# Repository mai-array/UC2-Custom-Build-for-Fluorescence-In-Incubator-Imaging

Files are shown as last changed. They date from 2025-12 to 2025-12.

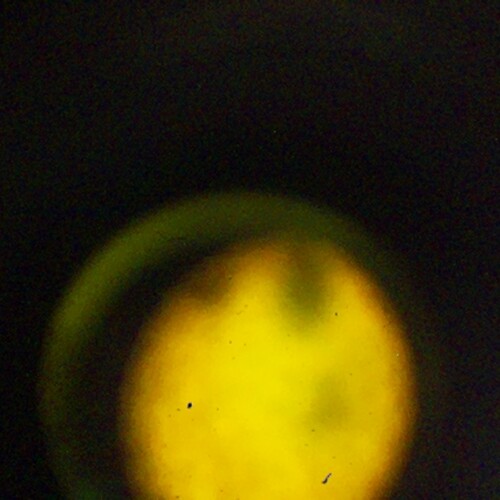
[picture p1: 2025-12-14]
Image Collections/Initial Attempts/PreIncTest/PreIncTest5.jpg

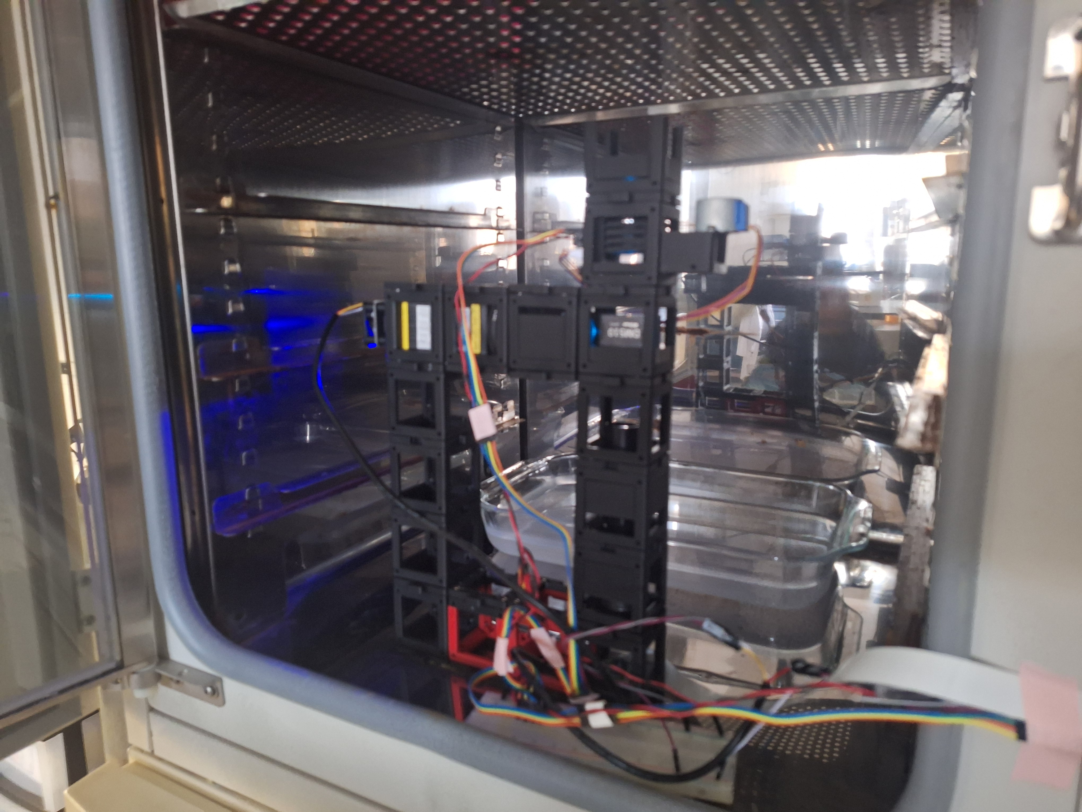
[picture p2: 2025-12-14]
Full Microscope Tests/in_incubator1.jpg

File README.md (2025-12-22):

A 3D Printed Modular Microscope for In-Incubator Time-lapse Fluorescence Imaging

Maitreyi Vadigepalli1,2, Kiril Bahadure1, Janice Walker1

1Department of Pathology and Genomic Medicine, Sidney Kimmel Medical College, Thomas Jefferson University, Philadelphia, PA

2Westtown School, Westtown, PA

We aim to develop a low-cost fluorescence microscope capable of obtaining time-lapse images of cell biology processes in vivo within a cell incubator setting. The commercial systems for fluorescence microscopy are expensive and require extensive setup for use in incubators. In recent years, 3D printing technology has enabled affordable alternatives to traditional frame structures and rigs, based on which multiple open-source frameworks have emerged for building low-cost, laboratory-grade microscopes. We used the open-source UC2 framework to develop a modular microscope tailored to fluorescent imaging within an incubator. We adopted standardized modules for the motor-controlled objective z-stepper, the Raspi camera, and a mirror, and developed custom-built modules for the laser, neutral density filter, beam expander, dichroic beamsplitter, tube lens, and sample holder. The initial version was built for benchtop imaging in a minimalist approach containing only a sample holder, objective, and Raspi camera module. This allowed us to optimize the software for controlling the motor to focus the objective. In subsequent iterations, we developed customized drop-in modules for fluorescent imaging. The current version features infinity optics, allowing placement of additional optical components between the camera and the objective. These modules can be combined in multiple ways based on the physical constraints of the incubator and the desired light path. The assembled microscope is controlled by a Raspberry Pi device. We developed Python code to control the objective z-stepper and the laser, as well as to coordinate between the two modules for automated time-lapse image capture. We are testing the system to image the cellular response to wounding in an ex vivo chick post-cataract surgery explant system, an established experimental model for studying the lens response to cataract surgery-induced wounding. We are visualizing cell boundaries using fluorescently conjugated Wheat Germ Agglutin, a lectin that demarcates cell membranes by binding GlcNAc and sialic acid residues. We are collecting images of the lens cellular response to wounding over 3 days, a typical period for wound closure. In summary, we demonstrate a modular, reconfigurable, 3D-printed microscope custom-built for in-incubator time-lapse fluorescence imaging for cell biology applications.

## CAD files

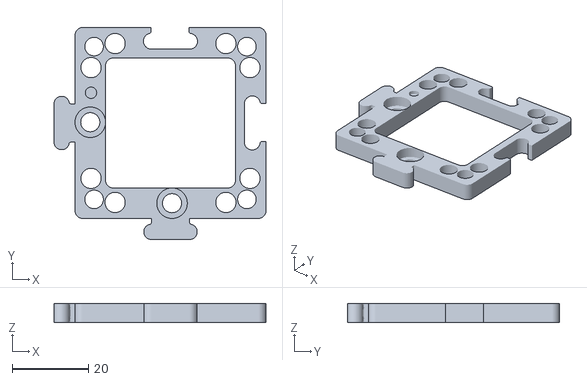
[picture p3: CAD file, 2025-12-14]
CAD Models/Cube + Baseplane - UC2/0_10_Base_puzzle_v3.stl
55.5 x 55.5 x 5.00

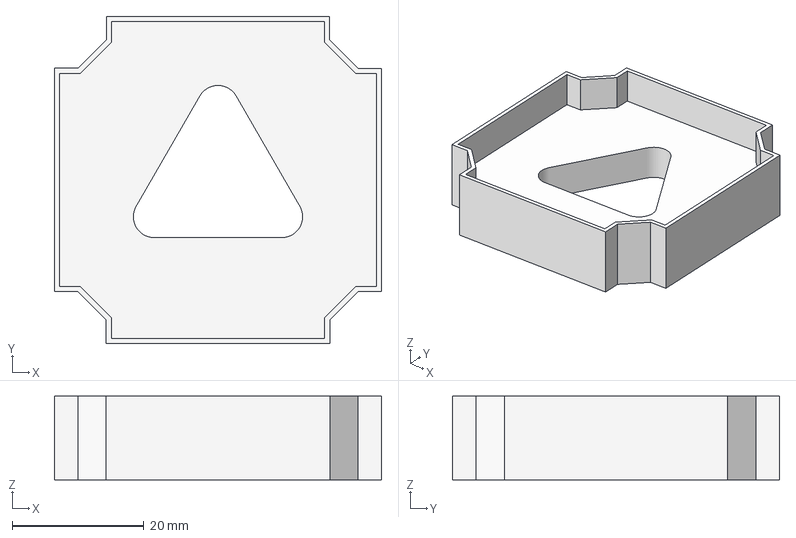
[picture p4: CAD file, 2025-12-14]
CAD Models/Sample Holder V5 - Custom.3mf
49.6 x 49.6 x 12.7 mm

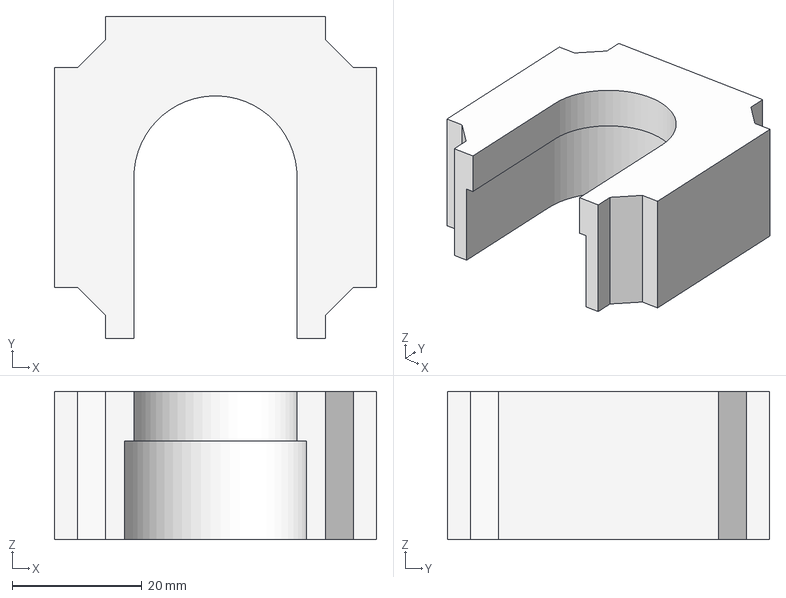
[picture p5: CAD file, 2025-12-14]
CAD Models/Tube Lens - Custom/Tube Lens P2 V2 - Custom.3mf
49.6 x 49.6 x 22.9 mm

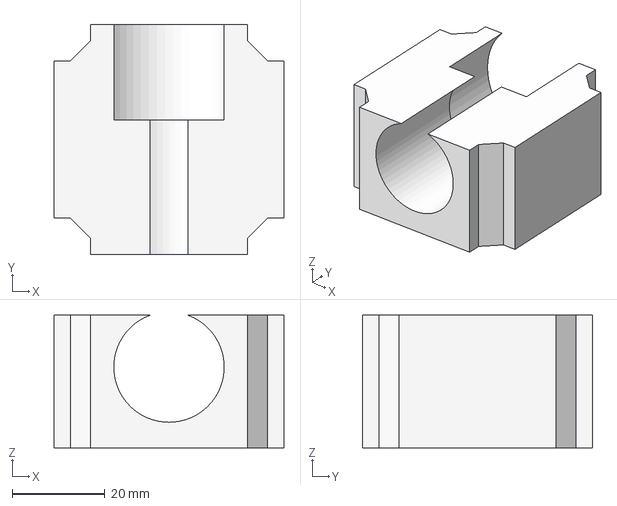
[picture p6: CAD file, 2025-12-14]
CAD Models/Beam Expander V2 - Custom.3mf
49.6 x 49.6 x 28.6 mm

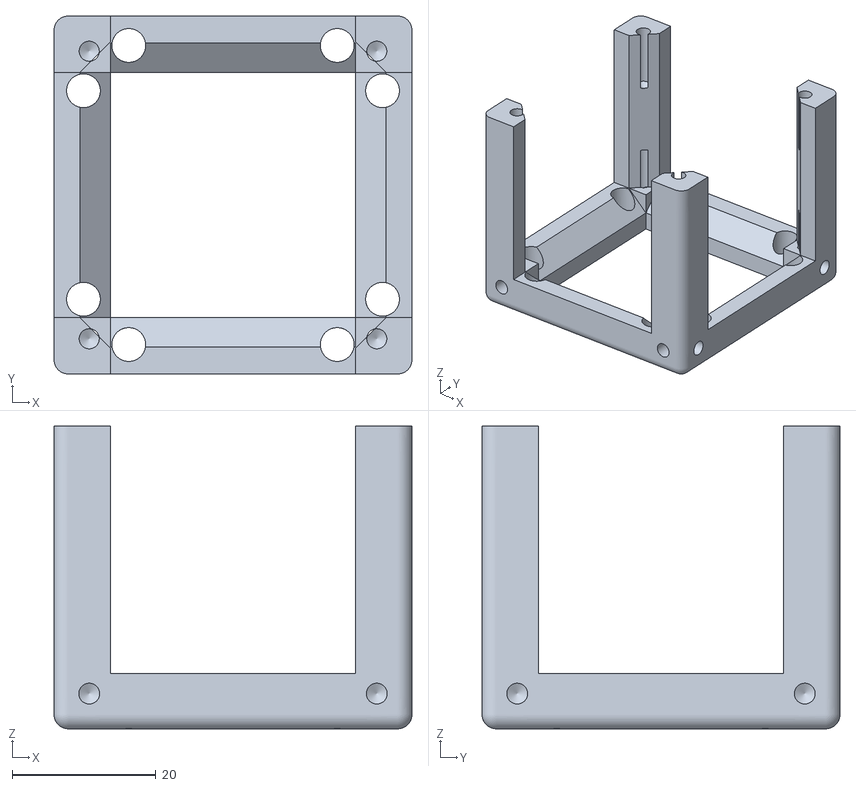
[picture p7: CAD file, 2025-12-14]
CAD Models/Cube + Baseplane - UC2/1_10_Cube_1x1_v3.stl
49.8 x 49.8 x 42.1

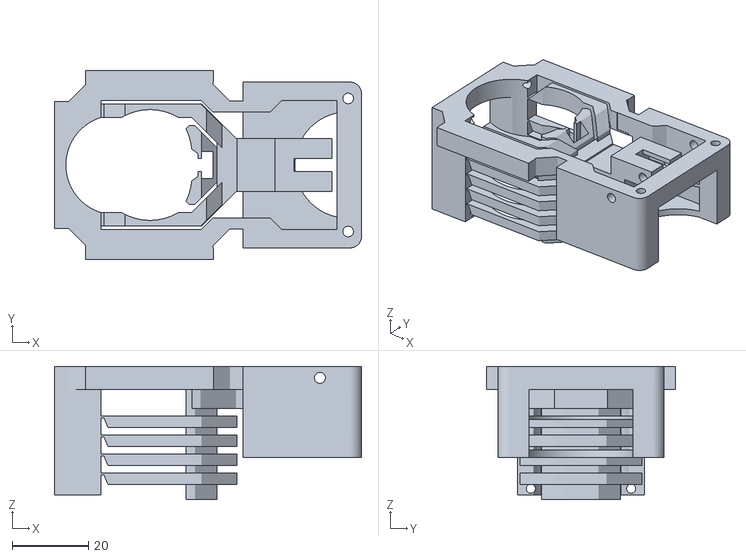
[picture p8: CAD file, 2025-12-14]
CAD Models/Objective Z-Stepper - UC2/2_20_focus_inlet_linearflexure_motorized_small_v3.stl
80.7 x 49.8 x 35.0

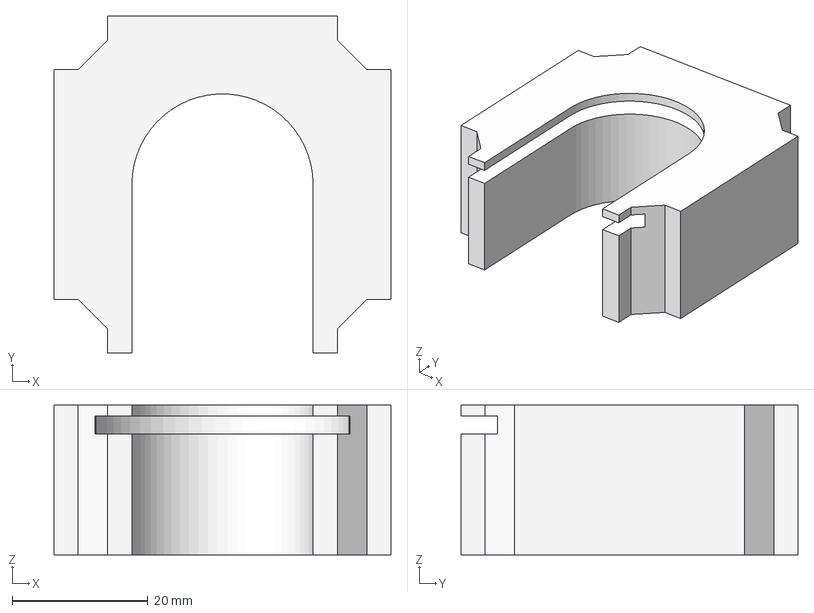
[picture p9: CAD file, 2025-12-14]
CAD Models/Tube Lens - Custom/Tube Lens P1 V2 - Custom.3mf
49.6 x 49.6 x 22.0 mm

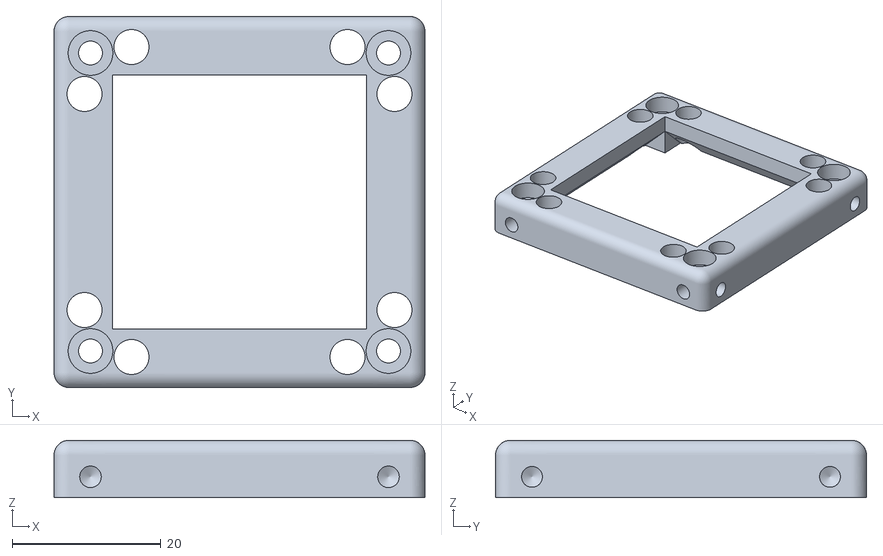
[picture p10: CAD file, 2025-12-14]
CAD Models/Cube + Baseplane - UC2/4_10_Lid_1x1_v3.stl
49.8 x 49.8 x 7.70

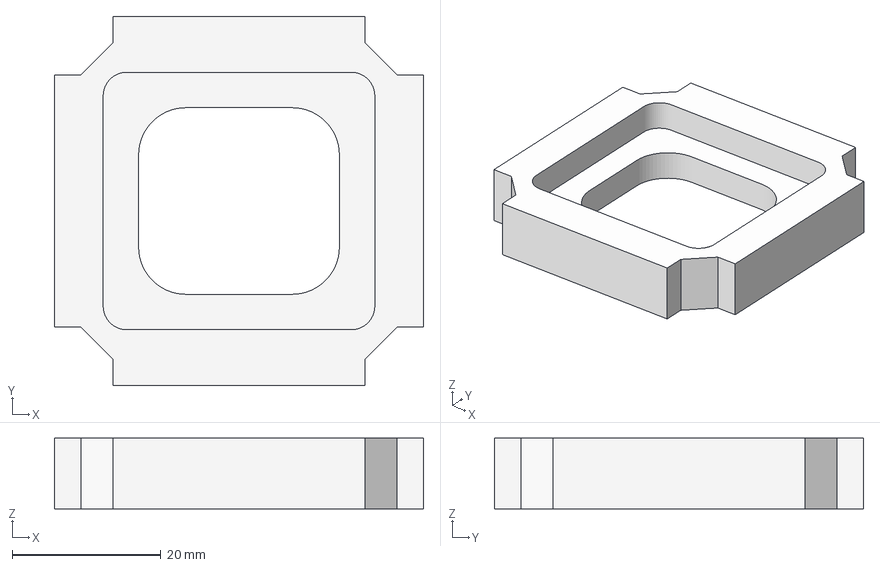
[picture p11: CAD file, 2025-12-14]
CAD Models/Dichroic Beam Splitter V5 - Custom.3mf
49.6 x 49.6 x 9.52 mm

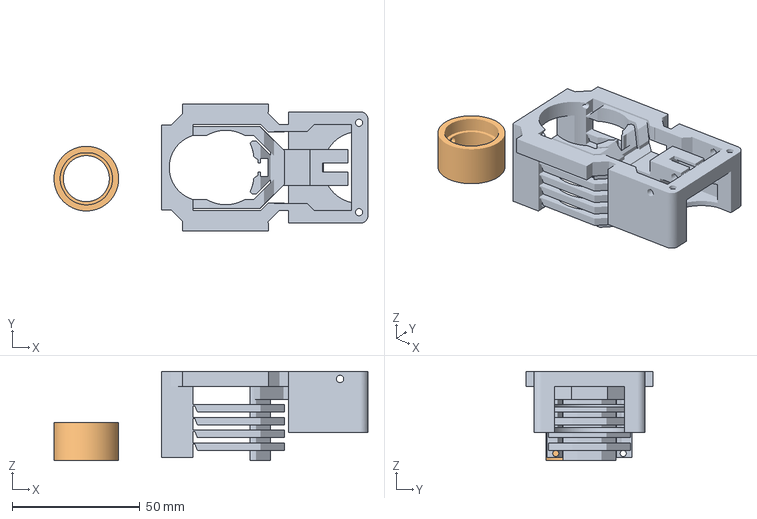
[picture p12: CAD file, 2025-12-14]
CAD Models/Objective Z-Stepper - UC2/0_20_focus_inlet_objective_mount_v8_v3.3mf
122.8 x 49.8 x 35.0 mm
2_20_focus_inlet_linearflexure_motorized_small_v3.stl
0_20_focus_inlet_objective_mount_v8_v3.stl

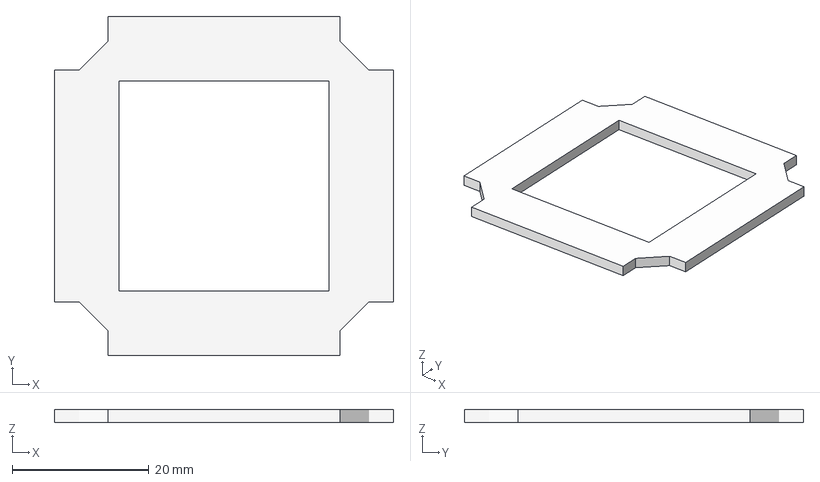
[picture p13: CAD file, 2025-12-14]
CAD Models/488nm Laser Mount V3 - Custom.3mf
49.6 x 49.6 x 1.90 mm

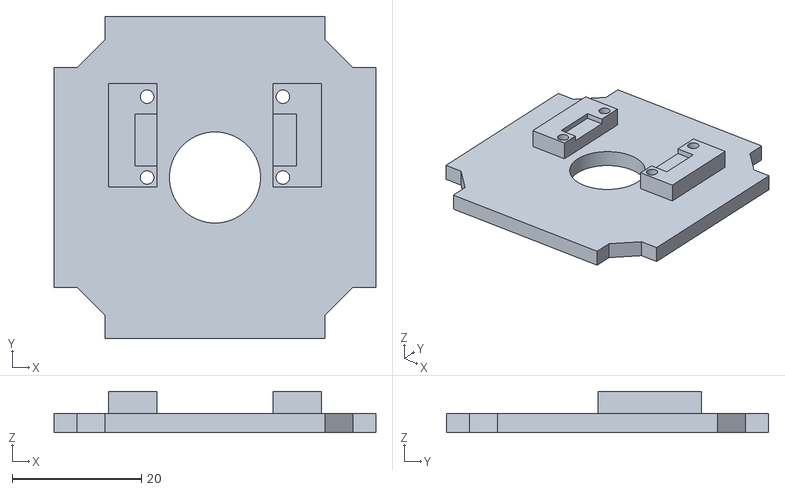
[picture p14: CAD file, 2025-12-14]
CAD Models/1_20_Cube_Insert_RaspiCam_v3 - UC2.stl
49.8 x 49.8 x 6.40

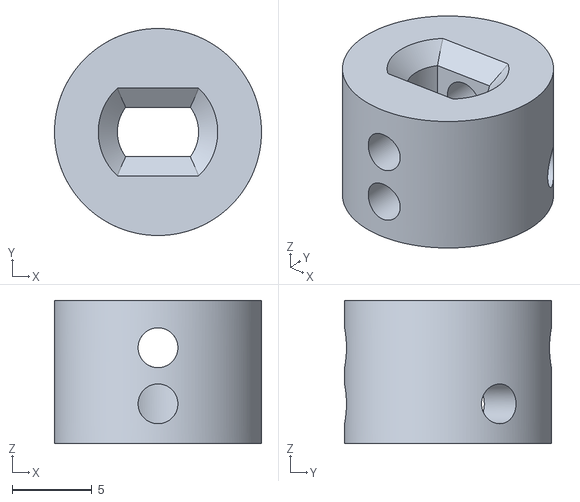
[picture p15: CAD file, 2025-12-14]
CAD Models/Objective Z-Stepper - UC2/3_30_Coupling_Screw_28BYJ_M3_v3.stl
13.0 x 13.0 x 9.00

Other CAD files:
CAD Models/Objective Z-Stepper - UC2/0_20_focus_inlet_objective_mount_v8_v3.stl

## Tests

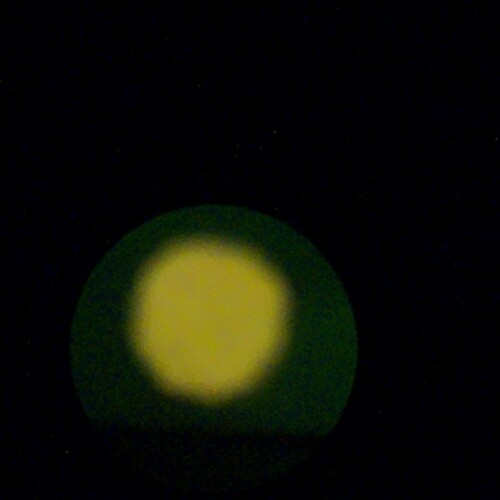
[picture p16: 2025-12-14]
Image Collections/Infinity Tests/1st Infinity Test/infinityTest7.jpg

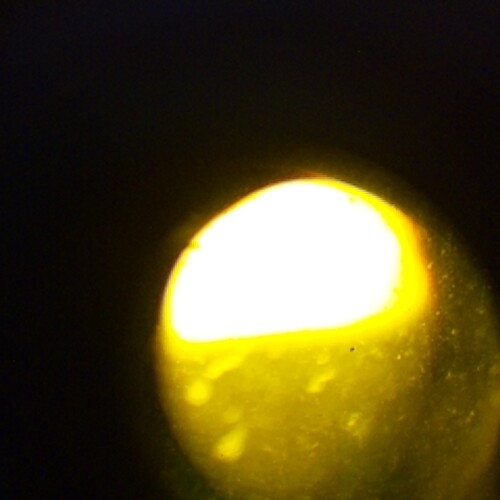
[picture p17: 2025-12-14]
Image Collections/Focusing Tests/focusTest1/focusTest14.jpg

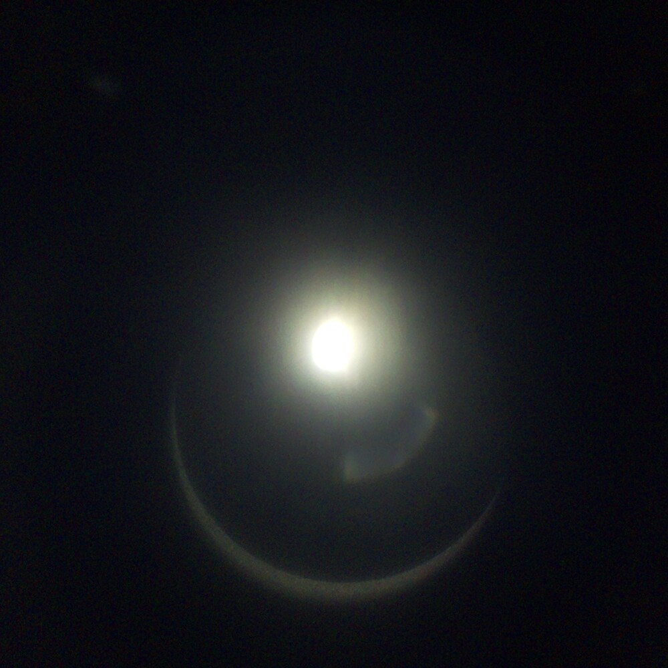
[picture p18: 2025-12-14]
Image Collections/Infinity Tests/1st Infinity Test/testimage.jpg

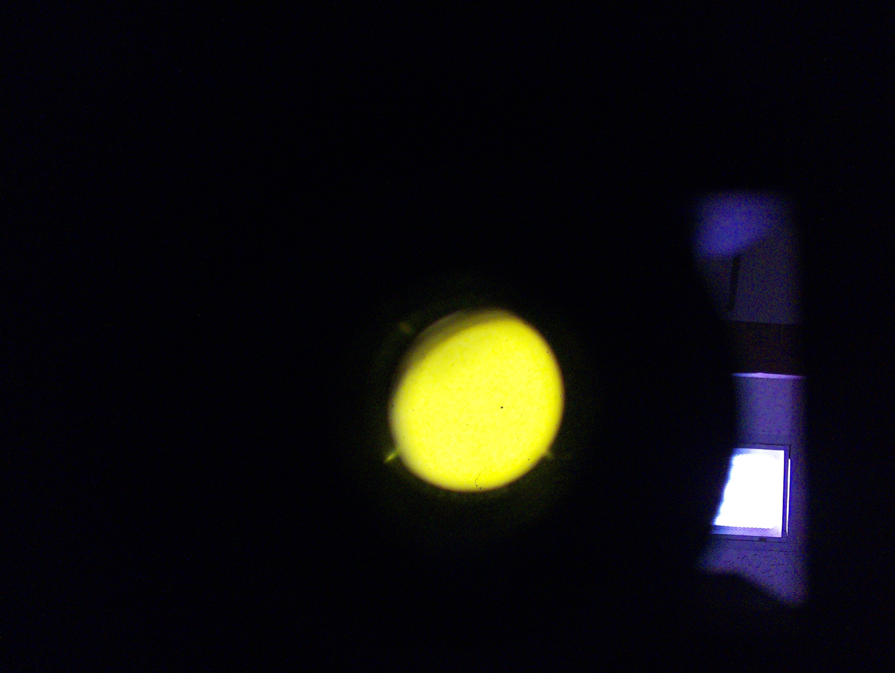
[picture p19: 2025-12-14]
Image Collections/Infinity Tests/2nd Infinity Test/infinityTestV2_6.jpg

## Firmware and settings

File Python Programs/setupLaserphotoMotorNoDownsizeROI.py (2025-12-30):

import RPi.GPIO as GPIO
import time
import os
from picamera2 import Picamera2

# -------------------- Camera Setup --------------------
home_dir = os.environ['HOME']
save_dir = os.path.join(home_dir, "Desktop")

picam2 = Picamera2()

# Sensor + ROI parameters (Camera Module v2 / IMX219)
SENSOR_WIDTH = 3280
SENSOR_HEIGHT = 2464

ROI_SIZE = 1000  # true sensor ROI, full resolution

ROI_X = (SENSOR_WIDTH - ROI_SIZE) // 2
ROI_Y = (SENSOR_HEIGHT - ROI_SIZE) // 2

# Configure the camera with full-res ROI
picam2.configure(
    picam2.create_still_configuration(
        main={"size": (ROI_SIZE, ROI_SIZE)}
    )
)

picam2.start()

# Lock camera settings (important for fluorescence & timelapse)
picam2.set_controls({
    "ScalerCrop": (ROI_X, ROI_Y, ROI_SIZE, ROI_SIZE),
    "ExposureTime": 10000,   # µs
    "AnalogueGain": 1.0,
    "AwbEnable": False
})

print("Camera initialized with true sensor ROI (1000×1000, no downscaling).")

# -------------------- GPIO Setup --------------------
GPIO.setmode(GPIO.BCM)

laser_pin = 18
GPIO.setup(laser_pin, GPIO.OUT, initial=GPIO.LOW)

# Stepper motor pins
IN1 = 2
IN2 = 3
IN3 = 4
IN4 = 17
control_pins = [IN1, IN2, IN3, IN4]

for pin in control_pins:
    GPIO.setup(pin, GPIO.OUT)
    GPIO.output(pin, 0)

# -------------------- Stepper Motor Sequence --------------------
step_sequence = [
    [1, 0, 0, 0],
    [1, 1, 0, 0],
    [0, 1, 0, 0],
    [0, 1, 1, 0],
    [0, 0, 1, 0],
    [0, 0, 1, 1],
    [0, 0, 0, 1],
    [1, 0, 0, 1]
]

STEPS_PER_REV = 2048
STEP_DELAY = 0.0015

# -------------------- Stepper Motor Function --------------------
def move_motor(steps, direction=1):
    sequence_len = len(step_sequence)
    for step in range(steps):
        for pin in range(4):
            index = step % sequence_len
            if direction == -1:
                index = (-step) % sequence_len
            GPIO.output(control_pins[pin], step_sequence[index][pin])
        time.sleep(STEP_DELAY)

# -------------------- Main Loop --------------------
img_count = 1

print("\nCommands:")
print(" - on / off   => Laser control")
print(" - pic        => Take photo (true ROI, high-res)")
print(" - cw / ccw   => Rotate motor")
print(" - exit       => Exit program")

try:
    while True:
        cmd = input("\nEnter command: ").strip().lower()

        if cmd == "on":
            GPIO.output(laser_pin, GPIO.HIGH)
            print("LASER ON")

        elif cmd == "off":
            GPIO.output(laser_pin, GPIO.LOW)
            print("LASER OFF")

        elif cmd == "pic":
            filename = f"ECZIncubatorTestsmalla{img_count}.jpg"
            filepath = os.path.join(save_dir, filename)

            picam2.capture_file(filepath)

            print(f"Captured {filename}")
            img_count += 1

        elif cmd == "cw":
            print("Rotating clockwise...")
            move_motor(STEPS_PER_REV, direction=1)

        elif cmd == "ccw":
            print("Rotating counterclockwise...")
            move_motor(STEPS_PER_REV, direction=-1)

        elif cmd == "exit":
            print("Exiting program...")
            break

        else:
            print("Invalid command. Use 'on', 'off', 'pic', 'cw', 'ccw', or 'exit'.")

except KeyboardInterrupt:
    print("\nInterrupted by user.")

finally:
    GPIO.cleanup()
    picam2.stop()
    print("GPIO cleaned up. Program ended.")

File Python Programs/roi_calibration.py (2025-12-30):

from picamera2 import Picamera2
import time

# -------------------- Sensor parameters (IMX219) --------------------
SENSOR_WIDTH = 3280
SENSOR_HEIGHT = 2464

# Initial ROI guess 
ROI_SIZE = 1000
ROI_X = (SENSOR_WIDTH - ROI_SIZE) // 2
ROI_Y = (SENSOR_HEIGHT - ROI_SIZE) // 2

# Movement controls
STEP = 20
ROI_MIN = 400
ROI_MAX = 2000

# -------------------- Camera Setup --------------------
picam2 = Picamera2()

picam2.configure(
    picam2.create_preview_configuration(
        main={"size": (800, 800)}
    )
)

picam2.start()

picam2.set_controls({
    "ScalerCrop": (ROI_X, ROI_Y, ROI_SIZE, ROI_SIZE),
    "ExposureTime": 10000,
    "AnalogueGain": 1.0,
    "AwbEnable": False
})

print("\n=== ROI CALIBRATION MODE ===")
print("w/s : move up / down")
print("a/d : move left / right")
print("+/- : resize ROI")
print("p   : print ROI values")
print("q   : quit\n")

# -------------------- Calibration Loop --------------------
while True:
    cmd = input("calib> ").strip().lower()

    if cmd == "w":
        ROI_Y = max(0, ROI_Y - STEP)
    elif cmd == "s":
        ROI_Y = min(SENSOR_HEIGHT - ROI_SIZE, ROI_Y + STEP)
    elif cmd == "a":
        ROI_X = max(0, ROI_X - STEP)
    elif cmd == "d":
        ROI_X = min(SENSOR_WIDTH - ROI_SIZE, ROI_X + STEP)
    elif cmd == "+":
        ROI_SIZE = min(ROI_MAX, ROI_SIZE + STEP)
    elif cmd == "-":
        ROI_SIZE = max(ROI_MIN, ROI_SIZE - STEP)
    elif cmd == "p":
        print(f"\nFINAL ROI → ({ROI_X}, {ROI_Y}, {ROI_SIZE}, {ROI_SIZE})\n")
        continue
    elif cmd == "q":
        print("\nExiting calibration.")
        break
    else:
        continue

    picam2.set_controls({
        "ScalerCrop": (ROI_X, ROI_Y, ROI_SIZE, ROI_SIZE)
    })

    print(f"ROI updated → ({ROI_X}, {ROI_Y}, {ROI_SIZE}, {ROI_SIZE})")

picam2.stop()

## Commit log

2025-12-14 Need to add python code asap
    [0_10_Base_puzzle_v3.stl, 0_20_focus_inlet_objective_mount_v8_v3.3mf, 0_20_focus_inlet_objective_mount_v8_v3.stl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]
2025-12-30 added calibration + true ROI no downsizing
